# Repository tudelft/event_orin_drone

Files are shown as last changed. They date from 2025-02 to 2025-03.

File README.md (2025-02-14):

# Event-Orin drone

drone

Overview repository for the Event-Orin drone.

```bash
git clone --recurse-submodules git@github.com:tudelft/event_orin_drone.git
```

Or without `--recurse-submodules` if you don't need PX4 etc.

## Repository structure

Airborne stuff:
- [fc](#fc): flight controller and software (PX4)
- [drone](#drone): drone parts and setup
- [orin](#orin): Jetson Orin setup and config
- [sensors](#sensors): sensor setup and config

Ground stuff:
- [gs](#gs): ground station software (QGroundControl)
- [sim](#sim): extras for PX4 simulation

Communication stuff:
- [comms](#comms): communication setup (MAVLink Router, uXRCE agent)
- [wifi](#wifi): wifi setup
- [radio](#radio): radio transmitter setup

ROS:
- [ros](#ros): ROS2 setup and config

Misc:
- [scripts](#scripts): some useful scripts for real-world flight
- [prints](#prints): 3D prints for the drone

If a folder/link doesn't exist, there's nothing there (yet).

Tested on:
- Ubuntu 22.04 (WSL) on Windows 11 with NVIDIA GPU
- Jetson Orin NX 16 GB with JetPack 6.0 and Jetson Linux 36.3

## System overview

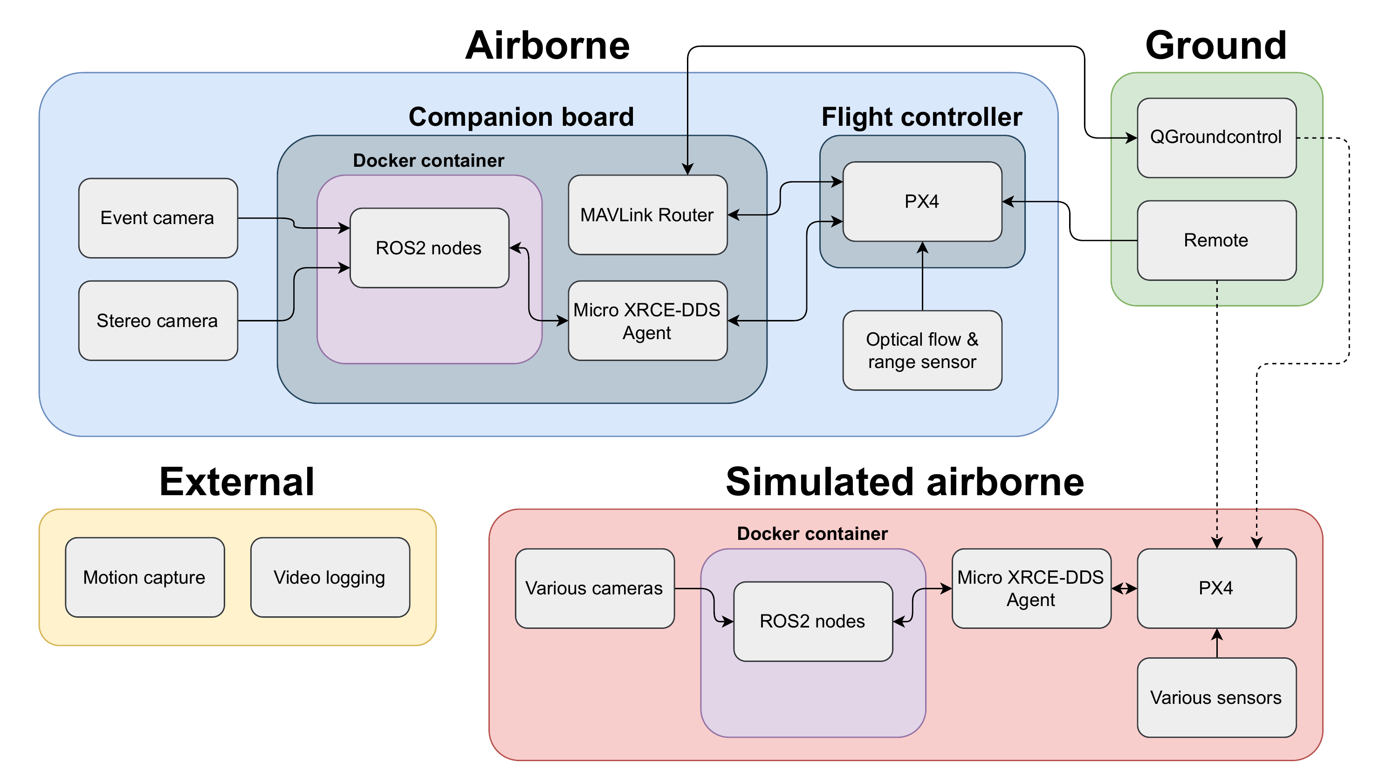
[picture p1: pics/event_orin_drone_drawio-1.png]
block diagram


## Components

### FC

- Holybro Kakute H7 Mini flight controller
- Disable ESC beeping/add a song:
    - [BLHeli Suite](https://github.com/bitdump/BLHeli/releases) (.zip file for windows)
    - Follow [this](https://oscarliang.com/connect-flash-blheli-32-esc/) guide roughly
        - No more flashing: [eol](https://oscarliang.com/end-of-blheli_32/#The-Issue-with-Firmware-Updates)
    - Add music: follow [this](https://oscarliang.com/blheli-32-custom-startup-tone-music/)
        - [Imperial march](https://www.youtube.com/watch?v=bsjB0JLju-0)
    - Disable inactivity beep: turn beacon strenth to zero as [here](https://drones.stackexchange.com/questions/2441/turn-off-beeping-of-esc-if-idle-for-some-time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,until%20it%20says%20%22Off%22)
- Flash Kakute H7 Mini flight controller with PX4 firmware
    - Initially has Betaflight, so use [Betaflight Configurator](https://github.com/betaflight/betaflight-configurator/releases) to flash the bootloader following [this](https://docs.px4.io/main/en/advanced_config/bootloader_update_from_betaflight.html)
        - Doesn't always work?
        - No DFU mode, no expert mode, [.hex bootloader file](fc/holybro_kakuteh7mini_bootloader.hex)
    - Build firmware: `make holybro_kakuteh7mini_default` (file [here](fc/holybro_kakuteh7mini_default.px4))
        - Note: this will fail if the correct tags are not checked out in the PX4 repo; to do so, run `git remote add upstream git@github.com:PX4/PX4-Autopilot.git && git fetch upstream && git fetch upstream --tags && git push --tags` following [this](https://github.com/PX4/PX4-Autopilot/issues/21644)
    - Flash with QGroundControl
    - Upload [parameter file](fc/event-orin.params)

### Drone

| **Component** | **Product** | **Mass [g]** | **Approx. power [W]** |
|---|---|---:|---:|
| Frame | Armattan Marmotte 5 inch | 455 | 200 |
| Motors | Emax ECO II Series 2306 | | |
| Propellers | Ethix S5 5 inch | | |
| Flight controller | Holybro Kakute H7 Mini | | |
| Optical flow & range sensor | MicoAir MTF-01 | | |
| ESC | Holybro Tekko32 F4 4in1 mini 50A BL32 | | |
| Battery | iFlight Fullsend 4S 3000mAh Li-Ion | 208 | - |
| On-board compute | NVIDIA Jetson Orin NX 16GB & DAMIAO v1.1 carrier board | 62 | 9 (`jtop`) |
| Event camera | iniVation DVXplorer Micro | 22 | [max 0.7](https://docs.inivation.com/_static/hardware_guides/dvxplorer-micro.pdf) |
| Stereo camera | Intel RealSense D435i | 75 | [max 3.5](https://www.intelrealsense.com/wp-content/uploads/2024/10/Intel-RealSense-D400-Series-Datasheet-October-2024.pdf) |
| **Total** | - | 822 | 213.2 |

### Orin

#### General

**TODO: add dts/dtb files**

- Jetson Orin NX 16GB module with [DAMIAO v1.1 carrier board](https://www.ebay.nl/sch/i.html?_nkw=DAMIAO+ORIN+NX+Carrier+Board&_sacat=0)
    - Careful installing the heat sink!
- Other hardware:
    - SSD: Corsair MP600 Core Mini
    - Wifi: Intel AX200 (add some antennas)
    - RTC battery: CR1220
    - Good XT30 power supply (used the one from A603 carrier board)
- Use [SDK manager](https://developer.nvidia.com/sdk-manager) to install JetPack 6.0
    - If not seen, make sure that it is in recovery mode (`lsusb` should show `NVIDIA Corp. APX`)
    - Select everything for installation
    - Select Jetson Orin NX 16GB with developer kit (even though it isn't)
    - **mavlab/mavlab** for login
    - If it doesn't work: try different cable! I had to retry a few times
        - Too hot? USB timeout? Cable?
- Update everything in GUI and with `apt update` (but don't yet `autoremove`)
- `hostnamectl set-hostname event-orin-drone`
- Configure wifi using `nmtui` or connect over ethernet for now (make sure to set to 'share to local' on Ubuntu)
- Configure orin:
    - Run [`configure_orin.sh`](orin/configure_orin.sh) as `cd orin && sudo ./configure_orin.sh`
    - Fixes wifi
        - Better version of [this](https://forums.developer.nvidia.com/t/jetpack-6-wifi-does-not-work-with-intel-ac-9260/292424)?
    - Sets fan to max on boot and MAXN power mode (0, [best performance[(https://docs.nvidia.com/jetson/archives/r36.3/DeveloperGuide/SD/PlatformPowerAndPerformance/JetsonOrinNanoSeriesJetsonOrinNxSeriesAndJetsonAgxOrinSeries.html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)])
- Enable extra UART following [these](https://forums.developer.nvidia.com/t/orin-nano-jetpack-6-0-uart1-issue/299825/8) [posts](https://forums.developer.nvidia.com/t/issue-with-enabling-uartb-serial-3110000-on-orin-nx-with-l4t-36-3/297052):
  - Decompile dtb to dts with `sudo dtc -I dtb -O dts A.dtb > A.dts`, modify, then recompile with `sudo dtc -I dts -O dtb A.dts > A.dtb`
  - Put in `/boot/dtb`, then specify the file in `/boot/extlinux/extlinux.conf` as in the posts, then reboot
- **DONT** install `jtop` ([instructions](https://github.com/rbonghi/jetson_stats)), this messes with the max fan above
- Check RTC: [here](https://ubuntu.com/core/docs/system-time)
- UARTs:
    - FC `telem1` (connector on FC) -> `/dev/ttyTHS1`: UART closest to carrier board edge
        - MAVLink Router
    - FC `telem2` (soldered on FC) -> `/dev/ttyTHS3`: UART closest to center of carrier board
        - uXRCE agent to ROS
    - For `telem2`, we'll use a baudrate of 3000000 (PX4 max, see [here](https://docs.px4.io/main/en/advanced_config/parameter_reference.html#SER_TEL1_BAUD)); for `telem1`, we'll use 921600 (else we got issues when controlling offboard)
        - No need to set it here, but be sure that the UART port/wires can support this
        - If too much, use something like 921600

#### `jetson-containers`

- Install [jetson-containers](https://github.com/dusty-nv/jetson-containers/blob/master/docs/setup.md)
- Build base image with e.g. `jetson-containers build --name event-orin cuda:12.2 pytorch:2.4 openai-triton:3.0.0`
- Check versions of installed packages, so you can get pre-built binaries from [here](http://jetson.webredirect.org/jp6/cu122)
- When running a container, it's nice to create a user with the same UID/GID inside, and use that, so not all folders will end up being owned by root: `jetson-containers run -v .:/workspace --user $(id -u):$(id -g) <container_name>`
- Example script for drone flight: see [here](scripts/drone_flight.sh)

### Sensors

#### General

- If you want to access sensors without `root` (whether inside or outside a container), we need to set some udev rules
- Use [sensors/unsafe_usb_udev.sh](sensors/unsafe_usb_udev.sh) (UNSAFE? but fine for Orin?) to open all USB ports for regular users
    - Test if this works
- On WSL, you need to share the USB device between Windows and WSL using [`usbipd-win`](https://github.com/dorssel/usbipd-win)
    - You can check if it's being detected in WSL with `lsusb`

#### MicoAir MTF-01

- Check that flow scale is set to 100 using [MicoAssistant](https://micoair.com/optical_range_sensor_mtf-01/)

#### Intel RealSense D435i

- Udev rules: [here](sensors/99-realsense-libusb.rules) from [here](https://github.com/IntelRealSense/librealsense/blob/master/config/99-realsense-libusb.rules)
- Build `librealsense` from source in Docker container following [here](https://github.com/dusty-nv/jetson-containers/blob/master/packages/hardware/realsense/Dockerfile)
    - Before, we had `realsense` in `jetson-containers`, but that still needed two fixes to allow `realsense` to build (from [here](https://github.com/dusty-nv/jetson-containers/issues/281#issuecomment-1874942046)).
    - Furthermore, `librealsense` libs should be loaded before any ROS2 ones, so we prepend to the `LD_LIBRARY_PATH` in the [`entrypoint.sh`](entrypoint.sh) script following [this comment](https://github.com/IntelRealSense/librealsense/issues/12831#issuecomment-2041140925).
- Run from Docker container using [`realsense-ros`](https://github.com/IntelRealSense/realsense-ros)
- Check if working with `rs-enumerate-devices`
- Could only get 15 Hz at 640x480 (even though 30 Hz should work?)

Configuration:
- Use [depth quality tool](https://github.com/IntelRealSense/librealsense/releases/tag/v2.56.2) to tune
    - Spatial, temporal and decimation filters with defaults
    - 640x40, 30 fps does work here, even with USB2.1
    - Both image and depth to auto-exposure
    - Align depth to color is nice
    - Further tips [here](https://dev.intelrealsense.com/docs/tuning-depth-cameras-for-best-performance#use-post-processing)

#### iniVation DVXplorer Micro

##### General

- Udev rules: [here](sensors/65-inivation.rules) from [here](https://gitlab.com/inivation/dv/libcaer/-/blob/master/docs/65-inivation.rules)
- Run from Docker container using [`libcaer_driver`](https://github.com/ros-event-camera/libcaer_driver) ROS packages
- Check if working with `ros2 launch libcaer_driver driver_node.launch.py`
- Works well, but seems to saturate for full resolution?

##### Camera calibration

- Could be done with a combination of [`simple_image_recon`](https://github.com/berndpfrommer/simple_image_recon) and [`camera_calibration`](https://docs.ros.org/en/rolling/p/camera_calibration/tutorial_mono.html), but it's easier to use [DV-GUI](https://docs.inivation.com/software/dv/gui/calibrate-event-camera.html) for this.
- Parameters that came out for our DVXplorer with 3.6mm lens can be found [here](sensors/dvx_calib_normal.xml)

### GS

Tested on Windows 11 with WSL (Ubuntu 22.04).

#### General

- [QGroundControl](https://github.com/mavlink/qgroundcontrol/releases) (stable, v4.4.2)
    - Install in Windows, else you can't flash
- Configure link to WSL: see [here](https://docs.px4.io/main/en/dev_setup/dev_env_windows_wsl.html)

#### Containers

- Install [Docker](https://docs.docker.com/engine/install/ubuntu/)
- Install [NVIDIA Container Toolkit](https://docs.nvidia.com/datacenter/cloud-native/container-toolkit/latest/install-guide.html)
- Install [jetson-containers](https://github.com/dusty-nv/jetson-containers/blob/master/docs/setup.md) (up to and including 'Docker default runtime')
    - On `aarch64`, `jetson-containers` automatically mounts USB devices, but this doesn't happen on [`x86_64`](https://github.com/dusty-nv/jetson-containers/blob/master/run.sh), so add `--device /dev/bus/usb`.

### Sim

If you want to run simulations with PX4 and Gazebo and ROS2:
- Install [PX4](fc/PX4-Autopilot/) following [this](https://docs.px4.io/main/en/dev_setup/dev_env_linux_ubuntu.html)
- ROS2 Humble following [this](https://docs.ros.org/en/humble/Installation/Ubuntu-Install-Debs.html)
- ROS2-Gazebo bridge for Gazebo Garden following [this](https://gazebosim.org/docs/latest/ros_installation/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)
- Micro XRCE-DDS Agent following [this](https://micro-xrce-dds.docs.eprosima.com/en/latest/installation.html#installation-from-snap-package) using `snap` with the `--edge` tag
    - Run with `snap run micro-xrce-dds-agent udp4 -p 8888`
- Connect radio as joystick, calibrate in Windows/QGroundControl
    - Joystick buttons: some issue [here](https://github.com/mavlink/qgroundcontrol/issues/4520)
- Simulation with depth camera messages sent to ROS2: [`sim/px4_gazebo_sim_example.sh`](sim/px4_gazebo_sim_example.sh)
- If you need it to work with a container, set `--ipc=host` following [this](https://github.com/eProsima/Fast-DDS/issues/2956)

### Comms

#### MAVLink Router

- For telemetry to ground station and logging (because PX4 cannot log to flash, and Kakute H7 Mini doesn't have SD...)
- Install [mavlink-router](https://github.com/mavlink-router/mavlink-router)
    - Make sure to add user to `dialout` and `tty` as [here](https://unix.stackexchange.com/questions/14354/read-write-to-a-serial-port-without-root)
- Put [config](comms/mavlink-router.conf) (from [here](https://bellergy.com/6-install-and-setup-mavlink-router/)) in `/etc/mavlink-router/main.conf`
- Run as `mavlink-routerd`
- Make sure to set up a TCP comms link in QGroundControl pointing to `<orin-ip-address:5760`
- Use sufficient baudrate (but not max PX4, this gives issues); we found 921600 to work well

#### uXRCE agent

- For communication between PX4 and ROS2
- Install following [this](https://micro-xrce-dds.docs.eprosima.com/en/latest/installation.html#installation-from-snap-package) using `snap`
- Run as `micro-xrce-dds-agent serial --dev /dev/ttyTHS3 -b 3000000` (match highest baudrate on PX4)

#### PX4-ROS2

- PX4-ROS2 interface lib as [here](https://docs.px4.io/main/en/ros2/px4_ros2_interface_lib.html)
- Works great
- Custom modes don't show up in QGroundControl v4.4.2 but you can still select them by overwriting PX4 default modes
    - In PX4 shell: `commander status` to see if registered, then `commander takeoff` and `commander mode auto:mission` to switch to the custom mode overwriting the PX4 'Mission' flight mode

### Wifi

- Antenna sticking out of the drone for better range
- Use Tailscale in combination with a hotspot
    - Fixed some problems: [this](https://tailscale.com/kb/1188/linux-dns)
    - eduroam seems too high latency?
- Key-only SSH, no root login
- Hotspot on laptop or phone (Windows: set to 2.4 GHz to maximize range)

**TODO: allow WSL to connect to drone without Tailscale (mirrored networking mode?), so we can have the OptiTrack client running on the laptop (else we need Zenoh bridge)**

### Radio

- ELRS, Radiomaster Pocket with EdgeTX, Radiomaster RP2
- Setup:
    - Update EdgeTx with [buddy](https://manual.edgetx.org/installing-and-updating-edgetx/update-from-opentx-to-edgetx-1), and doing reinstall in SD card content to get clean install
    - Go through all radio settings with [these](https://oscarliang.com/setup-radiomaster-pocket/) [posts](https://manual.edgetx.org/bw-radios)
    - Then continue here https://www.expresslrs.org/quick-start/transmitters/tx-prep/#radio-settings
    - Then update ELRS Tx firmware [here](https://www.expresslrs.org/quick-start/transmitters/updating/#via-etx-passthrough)
        - Better instructions [here](https://oscarliang.com/update-zorro-elrs-firmware/)
	- Configurator [here](https://www.expresslrs.org/quick-start/installing-configurator/)
	- **Bind phrase: `mavlab is cool`**
	- Receiver: follow [this](https://www.expresslrs.org/quick-start/receivers/updating/#manual-upload-via-ap)
    - Packet [rate](https://www.expresslrs.org/quick-start/transmitters/lua-howto/?h=packet#packet-rate-and-telemetry-ratio)
- Don't use MAVLink telemetry, just use CRSF protocol (link mode normal), packet rate 250Hz I think, switch mode wide, telem ratio std
    - Also check receiver via 'other devices' (?)
- Disable auto wifi interval: see [this](https://github.com/ExpressLRS/ExpressLRS/issues/1797) (annoying)

### ROS

- Contains ROS2 workspace, and script [build_ros2.sh](ros/build_ros.sh) to build ROS2 packages
- See [sim](#sim) for PX4-ROS2 setup

### Scripts

- [`drone_flight.sh`](scripts/drone_flight.sh): start all necessary windows/services for real flight
- [`move_logs_to_drive.sh`](scripts/move_logs_to_drive.sh): mount USB stick, move logs, unmount

## Examples

### Collecting data while flying

- Make sure containers, ROS, etc. are all built on the Orin
- Run [drone_flight.sh](scripts/drone_flight.sh) on the Orin (connect over SSH) to start all necessary services
- Connect to your local QGroundControl by setting up a comms link in QGroundControl (under application settings -> comm links) pointing to `<orin-ip-address>:5760` over TCP
- Make sure flight modes are set correctly in QGroundControl
- Then do `ros2 launch eo_drone drone_flight_recorder.launch.py` on the Orin to start recording events and flight controller stuff to a rosbag
- Fly around (in position or stabilized mode) and land
- Stop the rosbag recording, close all windows
- Put USB stick in Orin, check its UUID, then modify/run [move_logs_to_drive.sh](scripts/move_logs_to_drive.sh) to move the logs to the USB stick
- Read using [Foxglove](https://foxglove.dev/) or convert to H5

### Testing external flight modes in simulation

- Make sure containers, ROS, etc. are all built locally
- Run [sim/px4_gazebo_sim_external_modes.sh](sim/px4_gazebo_sim_external_modes.sh) to start PX4 and Gazebo simulation
    - If you don't end up with 4 tmux windows, something went wrong, so check the commands in normal terminals to see the error messages
    - If there's something about timeout while waiting for FMU, increase the `sleep` in the script
    - The sim might be very slow; if so, try disabling the image bridge in the script (then the corresponding depth seeker won't work of course)
- You can connect a joystick with QGroundControl but it's not necessary, set up comms link to WSL as explained [here](https://docs.px4.io/main/en/dev_setup/dev_env_windows_wsl.html#qgroundcontrol-on-windows)
- In the PX4 terminal:
    - `commander status` to see if custom modes are registered
    - `commander takeoff` to take off
    - `commander mode ext1` to start the depth seeker based on a depth camera, which should avoid the walls
    - `commander mode auto:loiter` to hover again, or `commander mode posctl` to control using the sticks
    - `commander mode ext2` to start flying a square autonomously

### Using a neural network for estimation/control

- Same as above, but now the external control node takes the output of a Python node running a PyTorch neural network
    - The network mimics a depth estimation network, taking an image and predicting a depth map
    - It is untrained, however, so it won't work very well (just to illustrate the concept)
- Run [sim/px4_gazebo_sim_network_control.sh](sim/px4_gazebo_sim_network_control.sh) to start PX4 and Gazebo simulation
- In the PX4 terminal:
    - `commander mode ext1` to start the depth seeker based on a depth estimation network, which shouldn't work well (because untrained)

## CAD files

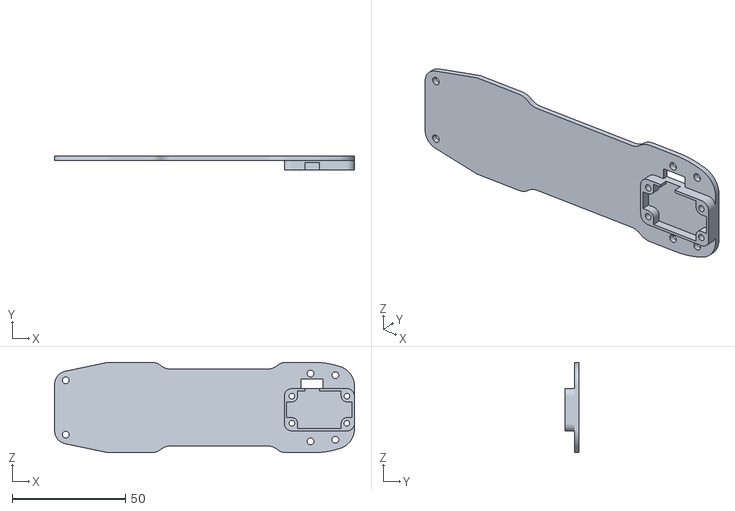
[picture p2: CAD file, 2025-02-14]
prints/bottom_plate.stl
132.7 x 6.00 x 40.0

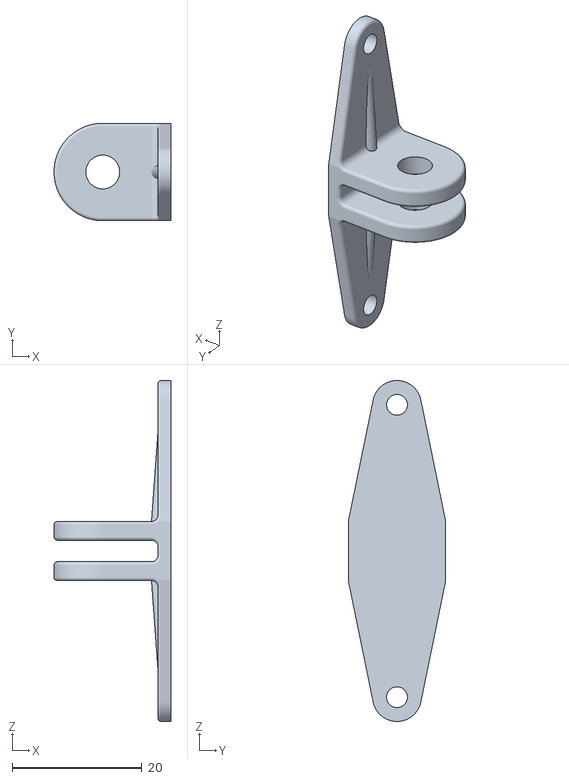
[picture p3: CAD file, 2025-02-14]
prints/realsense_attachement.stl
18.0 x 15.0 x 52.5

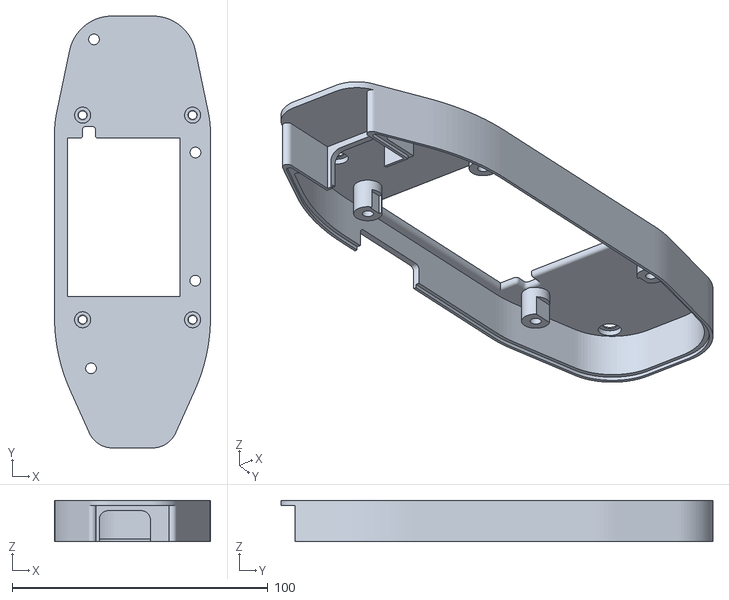
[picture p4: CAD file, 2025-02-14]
prints/top.stl
61.0 x 168.9 x 16.1

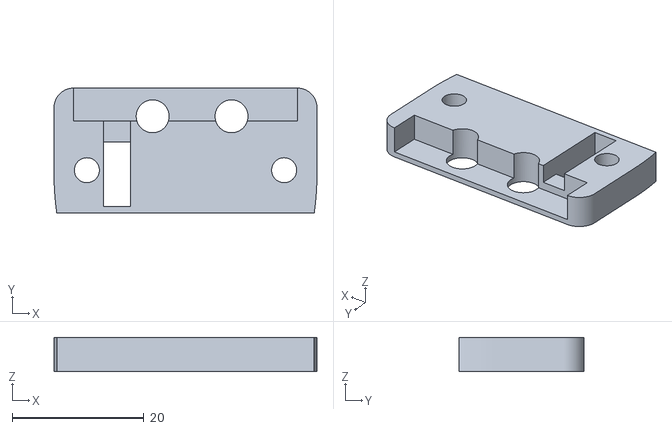
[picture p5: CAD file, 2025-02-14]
prints/spacer_for_cam_mount.stl
40.0 x 19.0 x 5.20

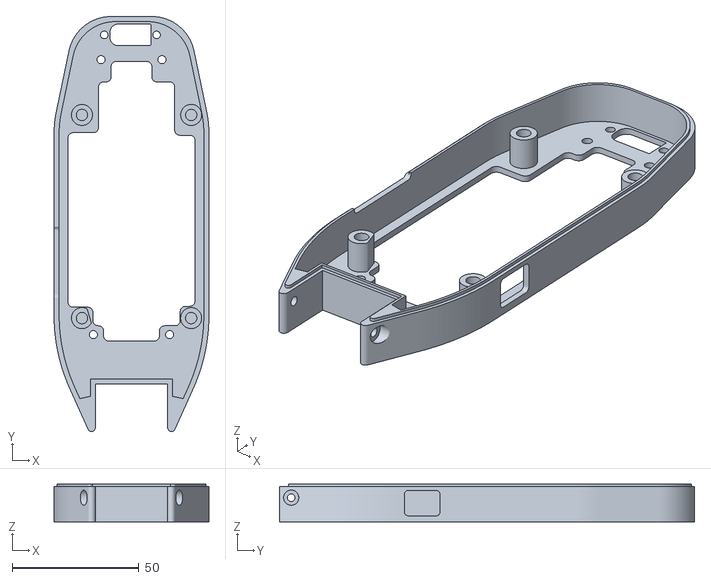
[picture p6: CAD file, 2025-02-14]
prints/bottom.stl
61.0 x 163.4 x 14.9

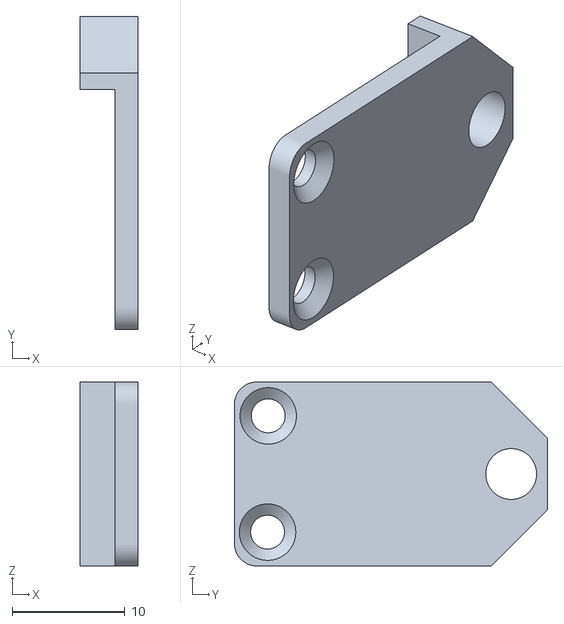
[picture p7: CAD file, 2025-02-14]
prints/camera_holder.stl
5.10 x 27.8 x 16.3

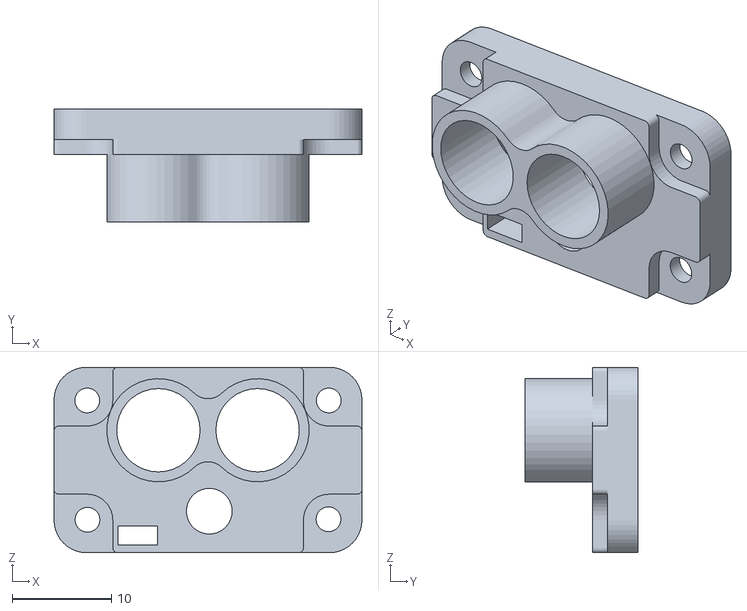
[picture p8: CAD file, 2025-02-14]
prints/flow_shell.stl
31.1 x 11.4 x 18.7

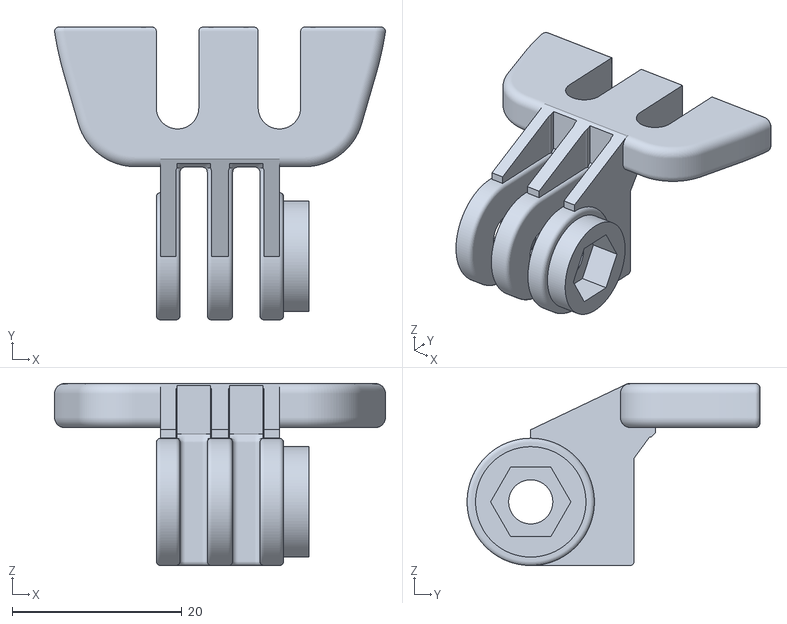
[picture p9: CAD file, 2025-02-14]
prints/realsense_holder_removable.stl
39.0 x 34.5 x 21.5

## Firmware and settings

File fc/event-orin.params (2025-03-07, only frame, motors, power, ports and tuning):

1	1	BAT1_A_PER_V	59.500000000000000000	9
1	1	BAT1_CAPACITY	-1.000000000000000000	9
1	1	BAT1_I_CHANNEL	-1	6
1	1	BAT1_N_CELLS	4	6
1	1	BAT1_R_INTERNAL	0.004999999888241291	9
1	1	BAT1_SOURCE	0	6
1	1	BAT1_V_CHANNEL	-1	6
1	1	BAT1_V_CHARGED	4.050000190734863281	9
1	1	BAT1_V_DIV	11.199999809265136719	9
1	1	BAT1_V_EMPTY	3.599999904632568359	9
1	1	BAT1_V_LOAD_DROP	0.100000001490116119	9
1	1	BAT_AVRG_CURRENT	15.000000000000000000	9
1	1	BAT_CRIT_THR	0.070000000298023224	9
1	1	BAT_EMERGEN_THR	0.050000000745058060	9
1	1	BAT_LOW_THR	0.150000005960464478	9
1	1	BAT_N_CELLS	3	6
1	1	BAT_V_CHARGED	4.050000190734863281	9
1	1	BAT_V_EMPTY	3.599999904632568359	9
1	1	BAT_V_LOAD_DROP	0.300000011920928955	9
1	1	BAT_V_OFFS_CURR	0.000000000000000000	9
1	1	CA_AIRFRAME	0	6
1	1	CA_ROTOR0_AX	0.000000000000000000	9
1	1	CA_ROTOR0_AY	0.000000000000000000	9
1	1	CA_ROTOR0_AZ	-1.000000000000000000	9
1	1	CA_ROTOR0_CT	6.500000000000000000	9
1	1	CA_ROTOR0_KM	0.050000000745058060	9
1	1	CA_ROTOR0_PX	0.079999998211860657	9
1	1	CA_ROTOR0_PY	0.090000003576278687	9
1	1	CA_ROTOR0_PZ	0.000000000000000000	9
1	1	CA_ROTOR10_AX	0.000000000000000000	9
1	1	CA_ROTOR10_AY	0.000000000000000000	9
1	1	CA_ROTOR10_AZ	-1.000000000000000000	9
1	1	CA_ROTOR10_CT	6.500000000000000000	9
1	1	CA_ROTOR10_KM	0.050000000745058060	9
1	1	CA_ROTOR10_PX	0.000000000000000000	9
1	1	CA_ROTOR10_PY	0.000000000000000000	9
1	1	CA_ROTOR10_PZ	0.000000000000000000	9
1	1	CA_ROTOR11_AX	0.000000000000000000	9
1	1	CA_ROTOR11_AY	0.000000000000000000	9
1	1	CA_ROTOR11_AZ	-1.000000000000000000	9
1	1	CA_ROTOR11_CT	6.500000000000000000	9
1	1	CA_ROTOR11_KM	0.050000000745058060	9
1	1	CA_ROTOR11_PX	0.000000000000000000	9
1	1	CA_ROTOR11_PY	0.000000000000000000	9
1	1	CA_ROTOR11_PZ	0.000000000000000000	9
1	1	CA_ROTOR1_AX	0.000000000000000000	9
1	1	CA_ROTOR1_AY	0.000000000000000000	9
1	1	CA_ROTOR1_AZ	-1.000000000000000000	9
1	1	CA_ROTOR1_CT	6.500000000000000000	9
1	1	CA_ROTOR1_KM	0.050000000745058060	9
1	1	CA_ROTOR1_PX	-0.079999998211860657	9
1	1	CA_ROTOR1_PY	-0.090000003576278687	9
1	1	CA_ROTOR1_PZ	0.000000000000000000	9
1	1	CA_ROTOR2_AX	0.000000000000000000	9
1	1	CA_ROTOR2_AY	0.000000000000000000	9
1	1	CA_ROTOR2_AZ	-1.000000000000000000	9
1	1	CA_ROTOR2_CT	6.500000000000000000	9
1	1	CA_ROTOR2_KM	-0.050000000745058060	9
1	1	CA_ROTOR2_PX	0.079999998211860657	9
1	1	CA_ROTOR2_PY	-0.090000003576278687	9
1	1	CA_ROTOR2_PZ	0.000000000000000000	9
1	1	CA_ROTOR3_AX	0.000000000000000000	9
1	1	CA_ROTOR3_AY	0.000000000000000000	9
1	1	CA_ROTOR3_AZ	-1.000000000000000000	9
1	1	CA_ROTOR3_CT	6.500000000000000000	9
1	1	CA_ROTOR3_KM	-0.050000000745058060	9
1	1	CA_ROTOR3_PX	-0.079999998211860657	9
1	1	CA_ROTOR3_PY	0.090000003576278687	9
1	1	CA_ROTOR3_PZ	0.000000000000000000	9
1	1	CA_ROTOR4_AX	0.000000000000000000	9
1	1	CA_ROTOR4_AY	0.000000000000000000	9
1	1	CA_ROTOR4_AZ	-1.000000000000000000	9
1	1	CA_ROTOR4_CT	6.500000000000000000	9
1	1	CA_ROTOR4_KM	0.050000000745058060	9
1	1	CA_ROTOR4_PX	0.000000000000000000	9
1	1	CA_ROTOR4_PY	0.000000000000000000	9
1	1	CA_ROTOR4_PZ	0.000000000000000000	9
1	1	CA_ROTOR5_AX	0.000000000000000000	9
1	1	CA_ROTOR5_AY	0.000000000000000000	9
1	1	CA_ROTOR5_AZ	-1.000000000000000000	9
1	1	CA_ROTOR5_CT	6.500000000000000000	9
1	1	CA_ROTOR5_KM	0.050000000745058060	9
1	1	CA_ROTOR5_PX	0.000000000000000000	9
1	1	CA_ROTOR5_PY	0.000000000000000000	9
1	1	CA_ROTOR5_PZ	0.000000000000000000	9
1	1	CA_ROTOR6_AX	0.000000000000000000	9
1	1	CA_ROTOR6_AY	0.000000000000000000	9
1	1	CA_ROTOR6_AZ	-1.000000000000000000	9
1	1	CA_ROTOR6_CT	6.500000000000000000	9
1	1	CA_ROTOR6_KM	0.050000000745058060	9
1	1	CA_ROTOR6_PX	0.000000000000000000	9
1	1	CA_ROTOR6_PY	0.000000000000000000	9
1	1	CA_ROTOR6_PZ	0.000000000000000000	9
1	1	CA_ROTOR7_AX	0.000000000000000000	9
1	1	CA_ROTOR7_AY	0.000000000000000000	9
1	1	CA_ROTOR7_AZ	-1.000000000000000000	9
1	1	CA_ROTOR7_CT	6.500000000000000000	9
1	1	CA_ROTOR7_KM	0.050000000745058060	9
1	1	CA_ROTOR7_PX	0.000000000000000000	9
1	1	CA_ROTOR7_PY	0.000000000000000000	9
1	1	CA_ROTOR7_PZ	0.000000000000000000	9
1	1	CA_ROTOR8_AX	0.000000000000000000	9
1	1	CA_ROTOR8_AY	0.000000000000000000	9
1	1	CA_ROTOR8_AZ	-1.000000000000000000	9
1	1	CA_ROTOR8_CT	6.500000000000000000	9
1	1	CA_ROTOR8_KM	0.050000000745058060	9
1	1	CA_ROTOR8_PX	0.000000000000000000	9
1	1	CA_ROTOR8_PY	0.000000000000000000	9
1	1	CA_ROTOR8_PZ	0.000000000000000000	9
1	1	CA_ROTOR9_AX	0.000000000000000000	9
1	1	CA_ROTOR9_AY	0.000000000000000000	9
1	1	CA_ROTOR9_AZ	-1.000000000000000000	9
1	1	CA_ROTOR9_CT	6.500000000000000000	9
1	1	CA_ROTOR9_KM	0.050000000745058060	9
1	1	CA_ROTOR9_PX	0.000000000000000000	9
1	1	CA_ROTOR9_PY	0.000000000000000000	9
1	1	CA_ROTOR9_PZ	0.000000000000000000	9
1	1	CA_ROTOR_COUNT	4	6
1	1	MC_PITCHRATE_D	0.001000000047497451	9
1	1	MC_PITCHRATE_FF	0.000000000000000000	9
1	1	MC_PITCHRATE_I	0.200000002980232239	9
1	1	MC_PITCHRATE_K	1.000000000000000000	9
1	1	MC_PITCHRATE_MAX	1200.000000000000000000	9
1	1	MC_PITCHRATE_P	0.079999998211860657	9
1	1	MC_PITCH_P	8.000000000000000000	9
1	1	MC_ROLLRATE_D	0.001000000047497451	9
1	1	MC_ROLLRATE_FF	0.000000000000000000	9
1	1	MC_ROLLRATE_I	0.200000002980232239	9
1	1	MC_ROLLRATE_K	1.000000000000000000	9
1	1	MC_ROLLRATE_MAX	1200.000000000000000000	9
1	1	MC_ROLLRATE_P	0.079999998211860657	9
1	1	MC_ROLL_P	8.000000000000000000	9
1	1	MC_YAWRATE_D	0.000000000000000000	9
1	1	MC_YAWRATE_FF	0.000000000000000000	9
1	1	MC_YAWRATE_I	0.100000001490116119	9
1	1	MC_YAWRATE_K	1.000000000000000000	9
1	1	MC_YAWRATE_MAX	600.000000000000000000	9
1	1	MC_YAWRATE_P	0.200000002980232239	9
1	1	MC_YAW_P	4.000000000000000000	9
1	1	MC_YAW_WEIGHT	0.400000005960464478	9
1	1	MOT_POLE_COUNT	14	6
1	1	MOT_SLEW_MAX	0.000000000000000000	9
1	1	PWM_MAIN_DIS1	1000	6
1	1	PWM_MAIN_DIS2	1000	6
1	1	PWM_MAIN_DIS3	1000	6
1	1	PWM_MAIN_DIS4	1000	6
1	1	PWM_MAIN_DIS5	1000	6
1	1	PWM_MAIN_DIS6	1000	6
1	1	PWM_MAIN_DIS7	1000	6
1	1	PWM_MAIN_DIS8	1000	6
1	1	PWM_MAIN_FAIL1	-1	6
1	1	PWM_MAIN_FAIL2	-1	6
1	1	PWM_MAIN_FAIL3	-1	6
1	1	PWM_MAIN_FAIL4	-1	6
1	1	PWM_MAIN_FAIL5	-1	6
1	1	PWM_MAIN_FAIL6	-1	6
1	1	PWM_MAIN_FAIL7	-1	6
1	1	PWM_MAIN_FAIL8	-1	6
1	1	PWM_MAIN_FUNC1	104	6
1	1	PWM_MAIN_FUNC2	101	6
1	1	PWM_MAIN_FUNC3	102	6
1	1	PWM_MAIN_FUNC4	103	6
1	1	PWM_MAIN_FUNC5	0	6
1	1	PWM_MAIN_FUNC6	0	6
1	1	PWM_MAIN_FUNC7	0	6
1	1	PWM_MAIN_FUNC8	0	6
1	1	PWM_MAIN_MAX1	1900	6
1	1	PWM_MAIN_MAX2	1900	6
1	1	PWM_MAIN_MAX3	1900	6
1	1	PWM_MAIN_MAX4	1900	6
1	1	PWM_MAIN_MAX5	2000	6
1	1	PWM_MAIN_MAX6	2000	6
1	1	PWM_MAIN_MAX7	2000	6
1	1	PWM_MAIN_MAX8	2000	6
1	1	PWM_MAIN_MIN1	1100	6
1	1	PWM_MAIN_MIN2	1100	6
1	1	PWM_MAIN_MIN3	1100	6
1	1	PWM_MAIN_MIN4	1100	6
1	1	PWM_MAIN_MIN5	1000	6
1	1	PWM_MAIN_MIN6	1000	6
1	1	PWM_MAIN_MIN7	1000	6
1	1	PWM_MAIN_MIN8	1000	6
1	1	PWM_MAIN_TIM0	-3	6
1	1	PWM_MAIN_TIM1	-3	6
1	1	PWM_MAIN_TIM2	-3	6
1	1	PWM_MAIN_TIM3	-3	6
1	1	SYS_AUTOSTART	4050	6

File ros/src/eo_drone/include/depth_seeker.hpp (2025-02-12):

/****************************************************************************
 * Copyright (c) 2023 PX4 Development Team.
 * SPDX-License-Identifier: BSD-3-Clause
 ****************************************************************************/
#pragma once

#include <Eigen/Core>
#include <algorithm>
#include <cmath>
#include <px4_ros2/components/mode.hpp>
#include <px4_ros2/control/setpoint_types/experimental/trajectory.hpp>
#include <px4_ros2/odometry/local_position.hpp>
#include <px4_ros2/utils/frame_conversion.hpp>
#include <px4_ros2/utils/geometry.hpp>
#include <rclcpp/rclcpp.hpp>
#include <std_msgs/msg/bool.hpp>
#include <std_msgs/msg/float32.hpp>
#include <std_msgs/msg/float32_multi_array.hpp>
#include <vector>

using namespace px4_ros2::literals;  // NOLINT

class DepthSeekerMode : public px4_ros2::ModeBase
{
public:
  explicit DepthSeekerMode(rclcpp::Node & node)
  : ModeBase(node, Settings{getName(node), false, static_cast<px4_ros2::ModeBase::ModeID>(getNavigationState(node))}),
    _inv_depth_bins(numDepthBins, 0.0f),
    _yaw_rate(0.0f),
    _forward_speed(0.0f),
    _status(false)
  {
    _inv_depth_bins_sub = node.create_subscription<std_msgs::msg::Float32MultiArray>(
      "~/avg_inv_depth", rclcpp::QoS(1).best_effort(),
      [this](std_msgs::msg::Float32MultiArray::SharedPtr msg) {
        _inv_depth_bins = msg->data;
        computeYawRate();
      });

    node.declare_parameter<double>("max_yaw_rate", 0.5);
    _max_yaw_rate = node.get_parameter("max_yaw_rate").as_double();

    _yaw_rate_pub = node.create_publisher<std_msgs::msg::Float32>("~/yaw_rate", 10);
    _forward_speed_pub = node.create_publisher<std_msgs::msg::Float32>("~/forward_speed", 10);
    _status_pub = node.create_publisher<std_msgs::msg::Bool>("~/status", 10);

    _trajectory_setpoint = std::make_shared<px4_ros2::TrajectorySetpointType>(*this);
    _vehicle_local_position = std::make_shared<px4_ros2::OdometryLocalPosition>(*this);
  }

  void onActivate() override
  {
    _state = State::Manoeuvre;
    _start_position_set = false;
    _status = true;
  }

  void onDeactivate() override { _status = false; }

  void updateSetpoint(float dt_s) override
  {
    if (!_start_position_set) {
      _start_position_m = _vehicle_local_position->positionNed();
      _start_position_set = true;
    }

    switch (_state) {
      case State::Manoeuvre: {
        // calc vertical speed based on offset from starting height
        // simple proportional control
        float vertical_speed =
          0.5f * (_start_position_m(2) - _vehicle_local_position->positionNed()(2));

        // update setpoint
        // trajectory: velocity and yaw rate in ned
        const Eigen::Vector3f target_velocity_m_s = px4_ros2::yawBodyToWorld(
          _vehicle_local_position->heading(), Eigen::Vector3f{forwardSpeed, 0.f, vertical_speed});
        _trajectory_setpoint->update(target_velocity_m_s, {}, {}, _yaw_rate);
      } break;
    }
  }

private:
  std::string getName(rclcpp::Node & node)
  {
    node.declare_parameter<std::string>("mode_name", "Depth Seeker");
    return node.get_parameter("mode_name").as_string();
  }

  static int getNavigationState(rclcpp::Node & node)
  {
    node.declare_parameter<std::string>("navigation_state", "ext1");
    std::string nav_state_str = node.get_parameter("navigation_state").as_string();

    // just allowing a couple of external modes for now
    if (nav_state_str == "ext1") {
      return px4_msgs::msg::VehicleStatus::NAVIGATION_STATE_EXTERNAL1;
    } else if (nav_state_str == "ext2") {
      return px4_msgs::msg::VehicleStatus::NAVIGATION_STATE_EXTERNAL2;
    } else if (nav_state_str == "ext3") {
      return px4_msgs::msg::VehicleStatus::NAVIGATION_STATE_EXTERNAL3;
    } else {
      RCLCPP_WARN(
        node.get_logger(), "Unknown navigation state: %s, defaulting to EXTERNAL1",
        nav_state_str.c_str());
      return px4_msgs::msg::VehicleStatus::NAVIGATION_STATE_EXTERNAL1;
    }
  }

  void computeYawRate()
  {
    // avg of center and side bins
    float center_idx = (numDepthBins - 1) / 2;
    // calculate yaw rate command
    float yaw_rate = 0;
    // only speed if steering
    float forward_speed = 0.0f;

    // avoid part
    float yaw_rate_avoid = 0;
    for (int i = 0; i < numDepthBins; i++) {
      float inv_depth_contrib = (center_idx - i) * std::exp(-constantObst / _inv_depth_bins[i]);
      float offset_contrib = std::exp(-std::pow(i - center_idx, 2) / (2 * sigma * sigma));
      yaw_rate_avoid += lambdaAvoid * inv_depth_contrib * offset_contrib;
    }

    // goal part
    // if multiple equal, chooses first
    int min_inv_depth_index = std::distance(
      _inv_depth_bins.begin(), std::min_element(_inv_depth_bins.begin(), _inv_depth_bins.end()));
    float yaw_rate_goal = lambdaGoal * (min_inv_depth_index - center_idx);

    // total
    yaw_rate = yaw_rate_avoid + yaw_rate_goal;
    forward_speed = forwardSpeed;

    // publish raw yaw rate
    std_msgs::msg::Float32 yaw_rate_msg;
    yaw_rate_msg.data = yaw_rate;
    _yaw_rate_pub->publish(yaw_rate_msg);

    // publish forward speed
    std_msgs::msg::Float32 forward_speed_msg;
    forward_speed_msg.data = forward_speed;
    _forward_speed_pub->publish(forward_speed_msg);

    // publish status
    std_msgs::msg::Bool status_msg;
    status_msg.data = _status;
    _status_pub->publish(status_msg);

    // limit yaw rate for control
    yaw_rate = std::max(-_max_yaw_rate, std::min(_max_yaw_rate, yaw_rate));

    // set computed yaw rate and speed to member variables
    _yaw_rate = yaw_rate;
    _forward_speed = forward_speed;
  }

  // TODO: make parameters
  static constexpr float forwardSpeed = 0.5f;  // forward speed during manoeuvre mode
  static constexpr int numDepthBins = 8;       // number of bins to bin the depth image to
  static constexpr float lambdaAvoid = 1.0f;   // original: 10; higher = smaller depths repulse more
  static constexpr float lambdaGoal = 0.2f;    // origina: 2; higher = larger depths attract more
  static constexpr float constantObst = 0.5f;  // scaling from depth of a bin to yaw rate
  static constexpr float sigma = 12.f;  // scaling from offset from center of a bin to yaw rate

  enum class State {
    Manoeuvre = 0,
  } _state;

  // NED earth-fixed frame
  Eigen::Vector3f _start_position_m;
  bool _start_position_set{false};

  std::vector<float> _inv_depth_bins;
  float _yaw_rate;
  float _max_yaw_rate;
  float _forward_speed;
  bool _status;

  rclcpp::Subscription<std_msgs::msg::Float32MultiArray>::SharedPtr _inv_depth_bins_sub;
  rclcpp::Publisher<std_msgs::msg::Float32>::SharedPtr _yaw_rate_pub;
  rclcpp::Publisher<std_msgs::msg::Float32>::SharedPtr _forward_speed_pub;
  rclcpp::Publisher<std_msgs::msg::Bool>::SharedPtr _status_pub;

  std::shared_ptr<px4_ros2::TrajectorySetpointType> _trajectory_setpoint;
  std::shared_ptr<px4_ros2::OdometryLocalPosition> _vehicle_local_position;
};

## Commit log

2024-11-27 add fc firmware
    [event-orin.params]
2024-11-27 flightmodes to posctl and mission
    [event-orin.params]
2024-12-03 latest params
    [event-orin.params]
2024-12-04 firmware with 100 hz dds
2024-12-12 higher logging rates
    [event-orin.params]
2024-12-13 fan to max on boot
2024-12-13 max fan cannot have jtop
2024-12-17 crank up baudrate
    [event-orin.params]
2024-12-17 sensor_combined to 400, motors to 1000, odometry to 200
2024-12-17 log hover thrust estimate
2024-12-17 no hover thrust
2024-12-17 back to lower ekf rates due to drift
    [event-orin.params]
2025-01-14 equal I gains
    [event-orin.params]
2025-01-23 building docker x86 and ros works
    [event-orin.params]
2025-02-12 lower baudrate, correct params
    [event-orin.params]
2025-02-14 stl files
    [bottom.stl, bottom_plate.stl, camera_holder.stl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]
2025-03-07 latest firmware
    [event-orin.params]
